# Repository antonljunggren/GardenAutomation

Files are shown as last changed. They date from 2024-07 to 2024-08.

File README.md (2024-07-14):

# Garden Automation System

A complete modular garden watering/monitoring system giving hobbyists and regular users a simple way to monitor and handle their gardens.

! STILL WIP !

## Overview
### Goals
In short, a complete system to handle everything from the sensors to the "cloud" automations

- Let users connect sensors in a simple way with a automated pairing process
- Be able to monitor the sensors on a dashboard
- Create automations or flows to let the system control sensors and outputs

## System Architecture
### Hardware

- Sensors will be simple MCUs like Attiny85 or similar (by using arduino supported MCUs a lot of problems will already been solved)
- A central hub consisting of a Raspberry Pi (hopefully a smaller Zero 2 will be sufficient enough)
- A CAN bus will be used for the communication between the devices and hub
- A perimiter wire that runs along the circumferense of the greenhouse that has: 24V power, CAN H & L and GND (24V for voltage drop, 12V, 5V & 3.3V are the target voltages on the devices/relays)

## Setup
To set up the raspberry pi we need to enable SPI and open a CAN bus interface in the boot config file. <br>
`dtparam=spi=on`<br>
`dtoverlay=mcp2515-can0,oscillator=16000000,interrupt=25,spimaxfrequency=1000000` <br>
`dtoverlay=spi-bcm2835-overlay`<br>

Then we install dotnet on the pi
`wget https://dot.net/v1/dotnet-install.sh -O dotnet-install.sh`<br>
`chmod +x dotnet-install.sh` <br>
`./dotnet-install.sh --channel 8.0 --install-dir /usr/share/dotnet` <br>
`export DOTNET_ROOT="/usr/share/dotnet"` <br>
`export PATH="$PATH:$DOTNET_ROOT"` <br>
`echo 'export DOTNET_ROOT=$HOME/.dotnet' >> ~/.bashrc` <br>
`echo 'export PATH=$PATH:$HOME/.dotnet' >> ~/.bashrc` <br>
`source ~/.bashrc` <br>

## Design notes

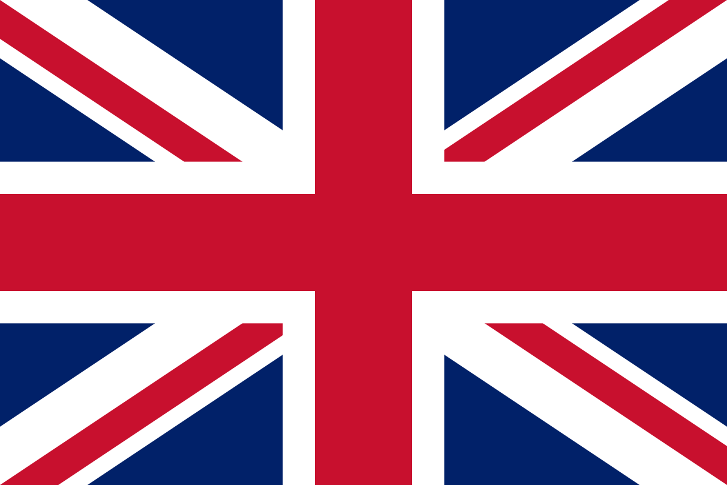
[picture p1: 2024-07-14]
Hub/src/WebAPI/Client/src/assets/uk_flag.png

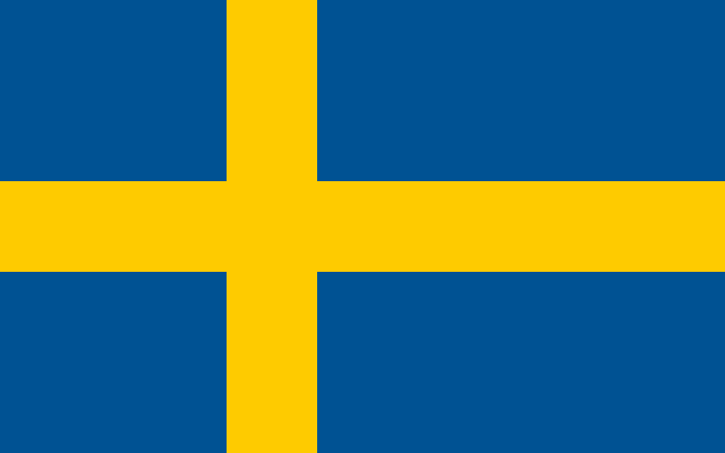
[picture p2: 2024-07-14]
Hub/src/WebAPI/Client/src/assets/swe_flag.png

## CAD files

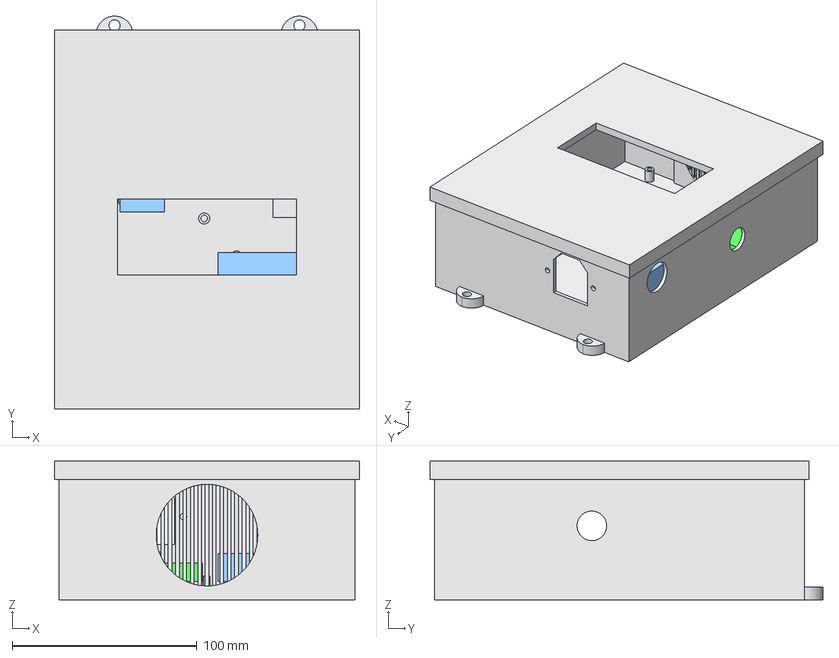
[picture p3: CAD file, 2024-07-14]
CAD/HubCad.FCStd
165.0 x 212.5 x 75.0 mm

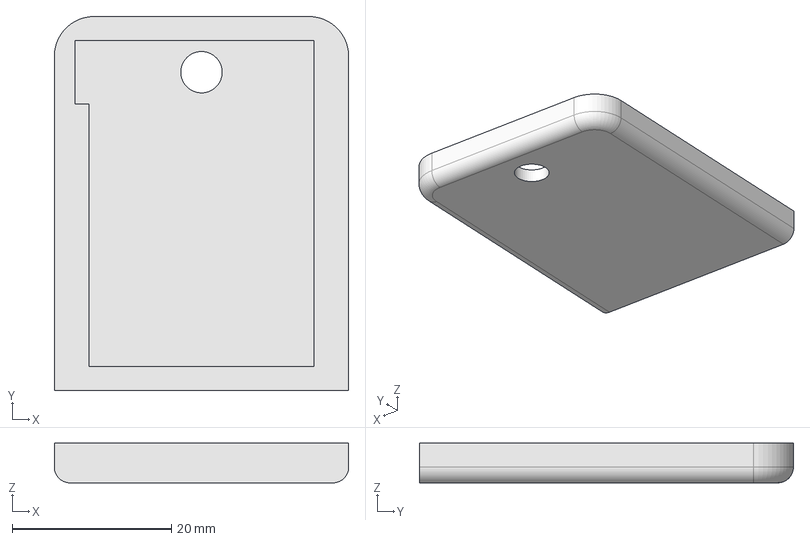
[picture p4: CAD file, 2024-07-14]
CAD/Generic_Attiny85_Sensor.FCStd
37.0 x 47.0 x 5.00 mm

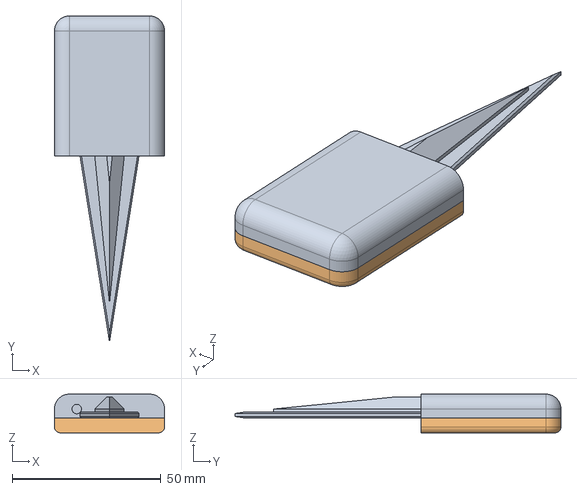
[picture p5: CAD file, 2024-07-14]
CAD/Attiny85_TemperatureSensor_Shell.FCStd
37.0 x 109.5 x 13.0 mm

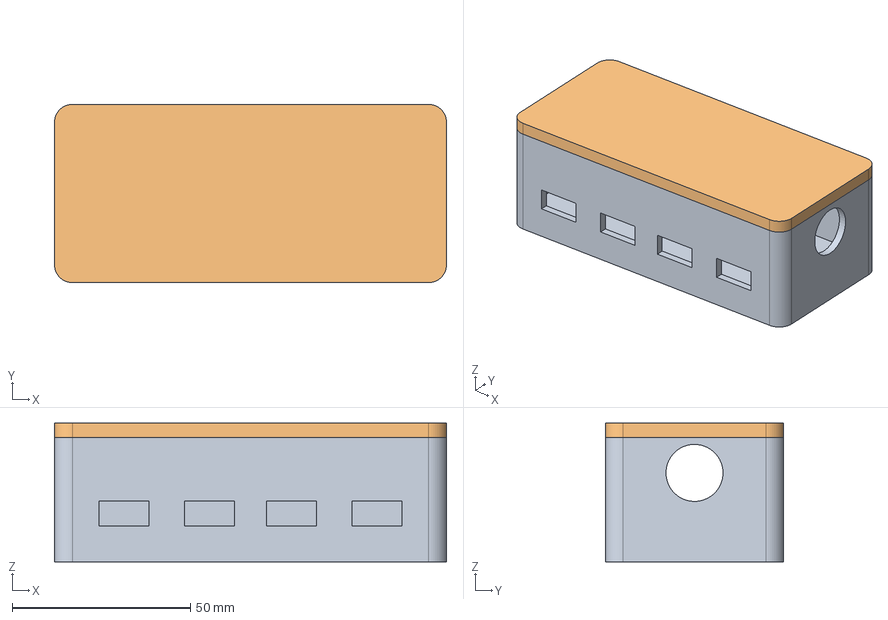
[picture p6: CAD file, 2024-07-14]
CAD/GatewayCAD.FCStd
110.0 x 50.0 x 39.0 mm

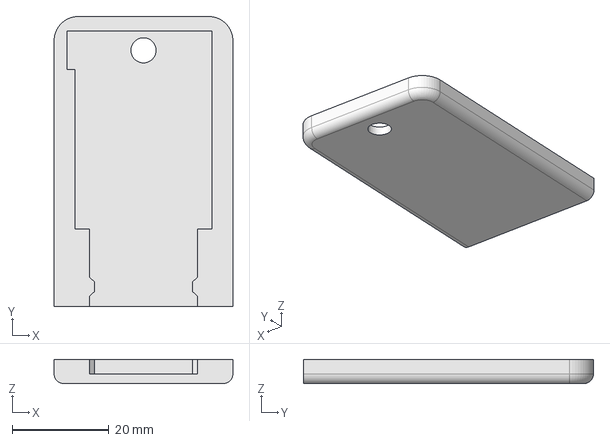
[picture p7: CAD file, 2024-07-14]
CAD/Attiny85_Soil_Moisture_Sensor.FCStd
37.0 x 60.0 x 5.00 mm

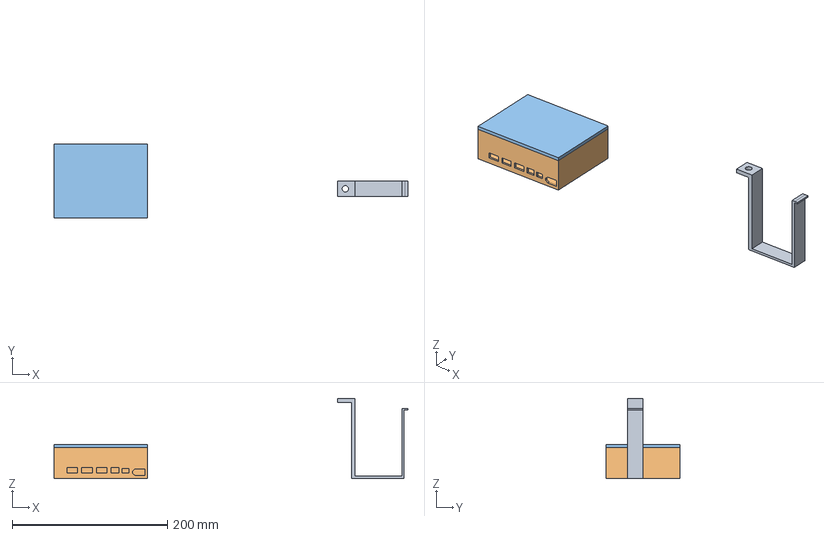
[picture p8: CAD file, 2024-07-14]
CAD/WaterPump.FCStd
455.5 x 95.0 x 103.0 mm

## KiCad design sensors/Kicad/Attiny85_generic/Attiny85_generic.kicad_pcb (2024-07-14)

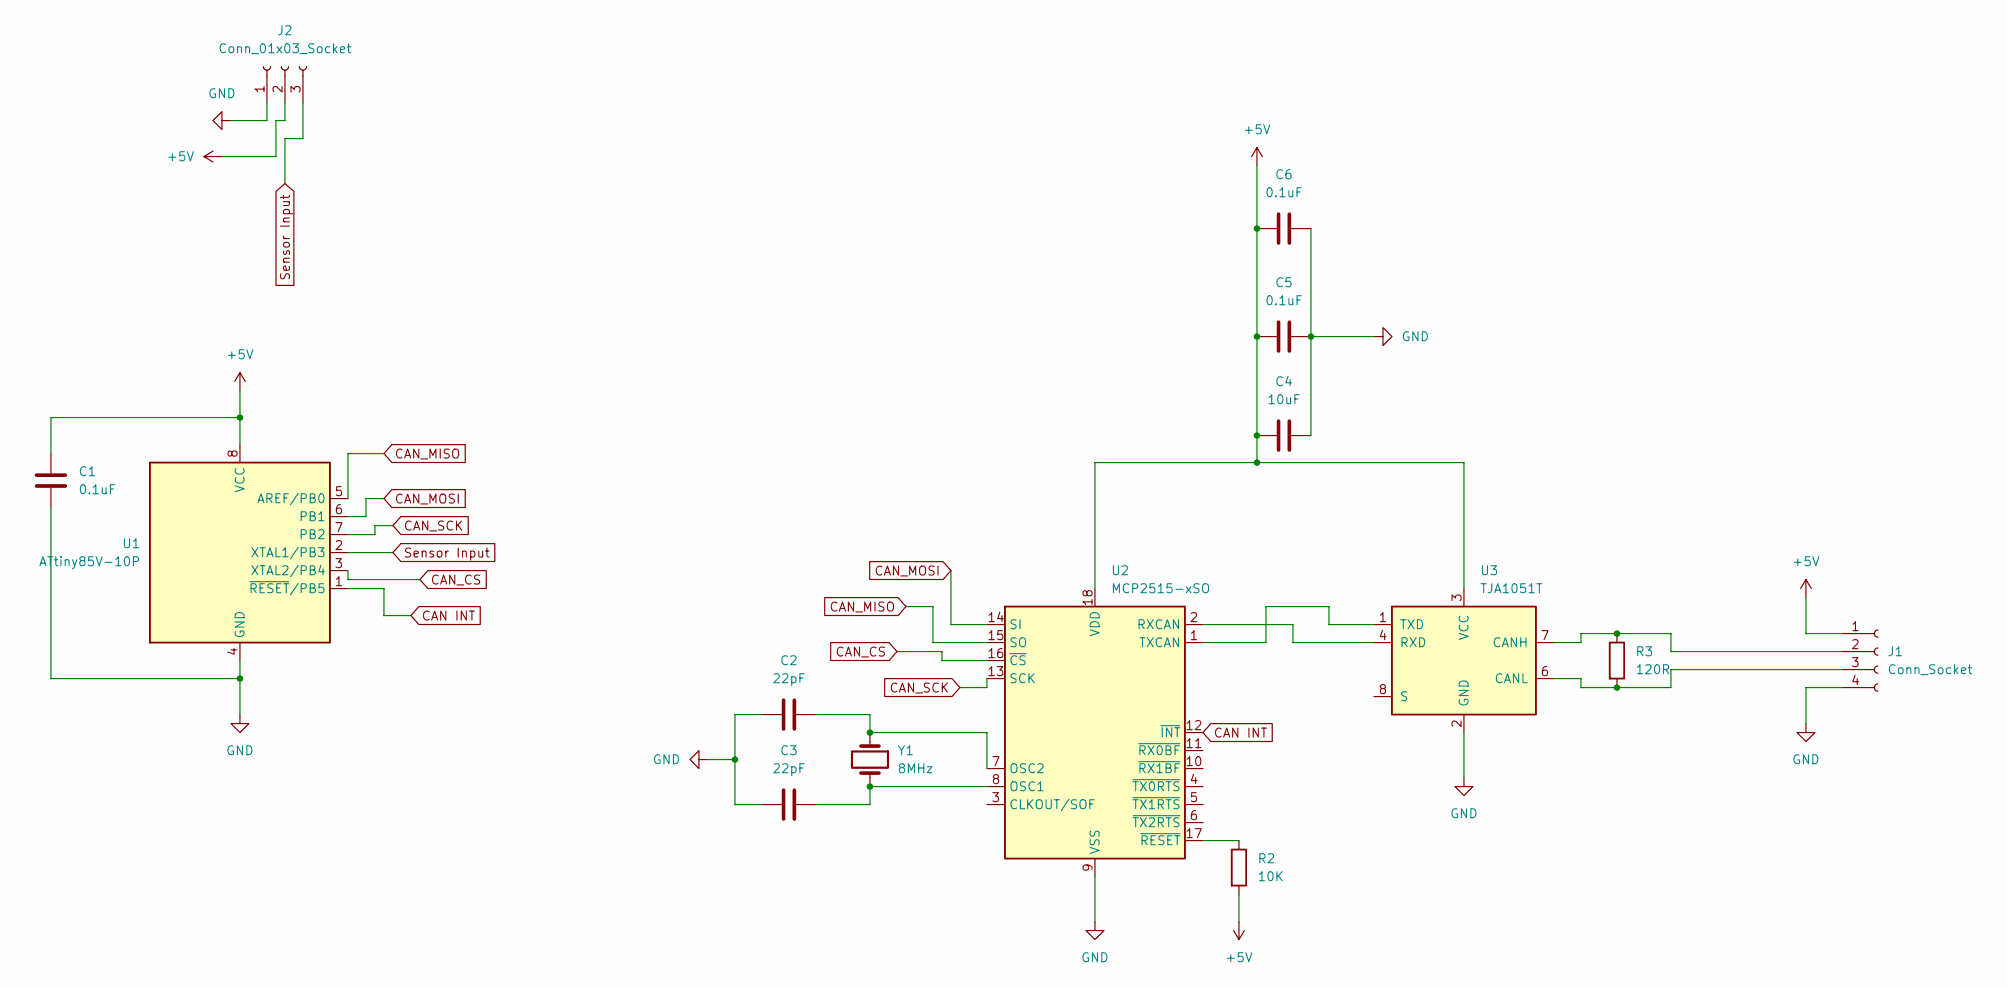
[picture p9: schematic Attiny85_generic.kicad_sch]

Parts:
C1, C5, C6: 0.1uF; C_0805_2012Metric_Pad1.18x1.45mm_HandSolder
C2, C3: 22pF; C_0805_2012Metric_Pad1.18x1.45mm_HandSolder
C4: 10uF; C_0805_2012Metric_Pad1.18x1.45mm_HandSolder
J1: Conn_Socket; PinHeader_1x04_P2.54mm_Vertical
J2: Conn_01x03_Socket; PinHeader_1x03_P2.54mm_Vertical
R2: 10K; R_0805_2012Metric_Pad1.20x1.40mm_HandSolder
R3: 120R; R_0805_2012Metric_Pad1.20x1.40mm_HandSolder
U1: ATtiny85V-10P; DIP-8_W7.62mm
U2: MCP2515-xSO; SOIC-18W_7.5x11.6mm_P1.27mm
U3: TJA1051T; SOIC-8_3.9x4.9mm_P1.27mm
Y1: 8MHz; Crystal_HC49-4H_Vertical

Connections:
+5V: C1.1, C4.2, C5.2, C6.2, J1.1, J2.2, R2.2, U1.8 (VCC), U2.18 (VDD), U3.3 (VCC)
CAN INT: U1.1 (~RESET/PB5), U2.12 (~INT)
CAN_CS: U1.3 (XTAL2/PB4), U2.16 (~CS)
CAN_MISO: U1.5 (AREF/PB0), U2.15 (SO)
CAN_MOSI: U1.6 (PB1), U2.14 (SI)
CAN_SCK: U1.7 (PB2), U2.13 (SCK)
GND: C1.2, C2.2, C3.2, C4.1, C5.1, C6.1, J1.4, J2.1, U1.4 (GND), U2.9 (VSS), U3.2 (GND)
unnamed: J1.2, R3.1, U3.7 (CANH)
unnamed: J1.3, R3.2, U3.6 (CANL)
unnamed: C3.1, U2.8 (OSC1), Y1.2
unnamed: C2.1, U2.7 (OSC2), Y1.1
unnamed: U2.2 (RXCAN), U3.4 (RXD)
unnamed: U2.1 (TXCAN), U3.1 (TXD)
unnamed: R2.1, U2.17 (~RESET)
Sensor Input: J2.3, U1.2 (XTAL1/PB3)

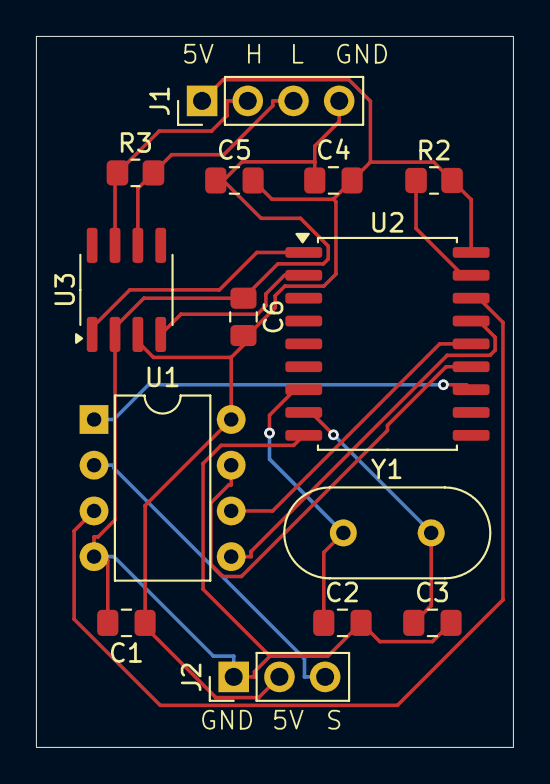
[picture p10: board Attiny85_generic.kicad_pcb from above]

Board: 2 copper layers, 26.5 x 39.5 mm, 14 parts (0 on the bottom side), 15 nets.

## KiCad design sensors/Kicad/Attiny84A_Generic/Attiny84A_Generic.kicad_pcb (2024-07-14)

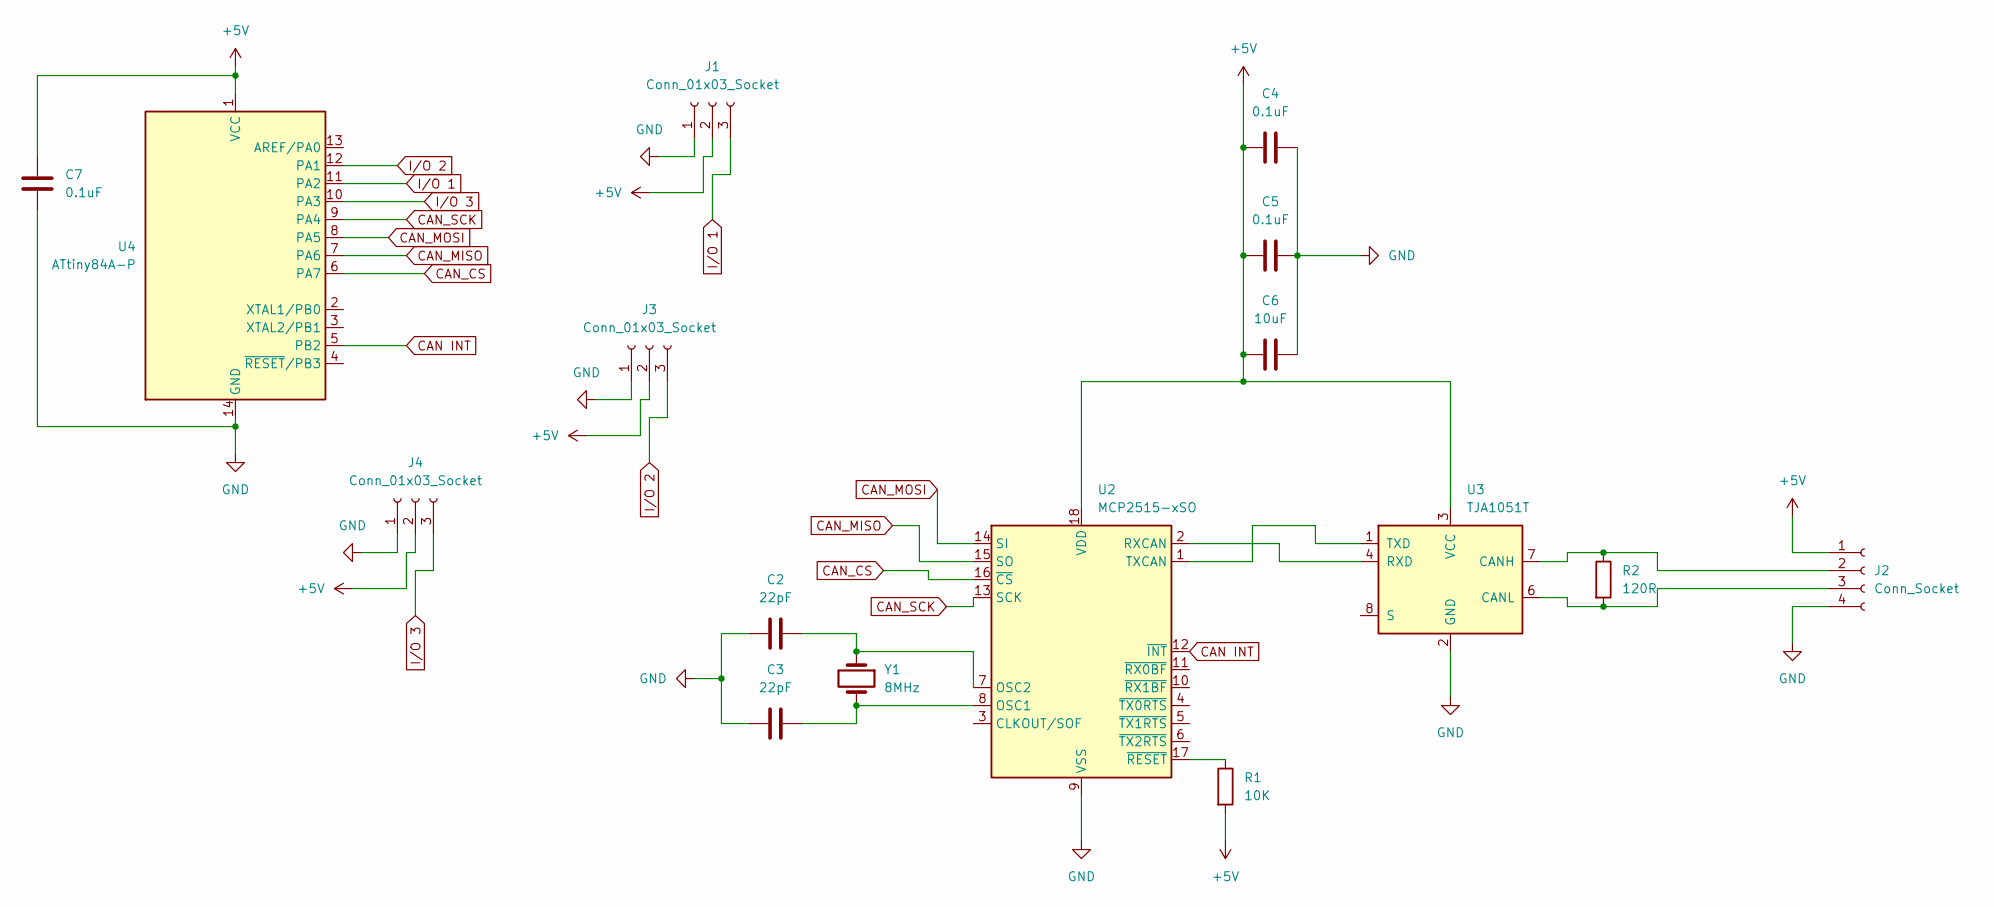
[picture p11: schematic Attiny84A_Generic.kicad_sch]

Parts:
C2, C3: 22pF; C_0805_2012Metric_Pad1.18x1.45mm_HandSolder
C4, C5, C7: 0.1uF; C_0805_2012Metric_Pad1.18x1.45mm_HandSolder
C6: 10uF; C_0805_2012Metric_Pad1.18x1.45mm_HandSolder
J1, J3, J4: Conn_01x03_Socket; PinHeader_1x03_P2.54mm_Vertical
J2: Conn_Socket; PinHeader_1x04_P2.54mm_Vertical
R1: 10K; R_0805_2012Metric_Pad1.20x1.40mm_HandSolder
R2: 120R; R_0805_2012Metric_Pad1.20x1.40mm_HandSolder
U2: MCP2515-xSO; SOIC-18W_7.5x11.6mm_P1.27mm
U3: TJA1051T; SOIC-8_3.9x4.9mm_P1.27mm
U4: ATtiny84A-P; DIP-14_W7.62mm
Y1: 8MHz; Crystal_HC49-4H_Vertical

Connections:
+5V: C4.2, C5.2, C6.2, C7.1, J1.2, J2.1, J3.2, J4.2, R1.2, U2.18 (VDD), U3.3 (VCC), U4.1 (VCC)
CAN INT: U2.12 (~INT), U4.5 (PB2)
CAN_CS: U2.16 (~CS), U4.6 (PA7)
CAN_MISO: U2.15 (SO), U4.7 (PA6)
CAN_MOSI: U2.14 (SI), U4.8 (PA5)
CAN_SCK: U2.13 (SCK), U4.9 (PA4)
GND: C2.2, C3.2, C4.1, C5.1, C6.1, C7.2, J1.1, J2.4, J3.1, J4.1, U2.9 (VSS), U3.2 (GND), U4.14 (GND)
I/O 1: J1.3, U4.11 (PA2)
I/O 2: J3.3, U4.12 (PA1)
I/O 3: J4.3, U4.10 (PA3)
unnamed: J2.2, R2.1, U3.7 (CANH)
unnamed: J2.3, R2.2, U3.6 (CANL)
unnamed: C3.1, U2.8 (OSC1), Y1.2
unnamed: C2.1, U2.7 (OSC2), Y1.1
unnamed: U2.2 (RXCAN), U3.4 (RXD)
unnamed: U2.1 (TXCAN), U3.1 (TXD)
unnamed: R1.1, U2.17 (~RESET)

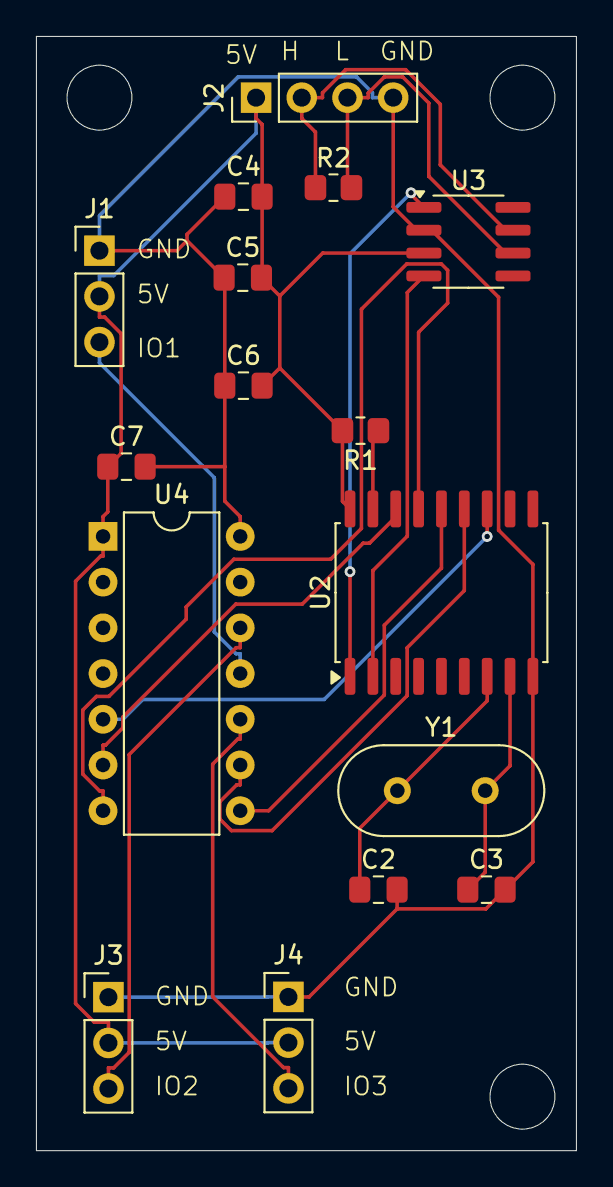
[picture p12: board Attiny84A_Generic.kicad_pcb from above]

Board: 2 copper layers, 30.0 x 61.9 mm, 16 parts (0 on the bottom side), 17 nets.

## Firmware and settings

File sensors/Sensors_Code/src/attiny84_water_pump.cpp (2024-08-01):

#include <sensor-device.h>
#include <EEPROM.h>

#define WATER_PUMP_PIN PIN_PA1
#define WATER_LEVEL PIN_PA3
#define WATER_LEVEL_STOP PIN_PA2

#define PUMP_CMD 0
#define SET_LOW_OFFSET_CMD 1
#define SET_MAX_OFFSET_CMD 2

#define DATA_WATER_LEVEL 0

#define NUMSAMPLES 10
int samples[NUMSAMPLES];

const int water_level_low_offset_address = 0;
const int water_level_max_offset_address = sizeof(int);

void dataReceived(CAN_Message msg);

int getWaterLevel();

void readFromEEPROM(int &low_offset, int &max_offset) {
  EEPROM.get(water_level_low_offset_address, low_offset);
  EEPROM.get(water_level_max_offset_address, max_offset);
}

bool is_pumping = false;

int lowOffset, maxOffset;

void setup()
{
    pinMode(WATER_PUMP_PIN, OUTPUT);
    pinMode(WATER_LEVEL, INPUT);
    pinMode(WATER_LEVEL_STOP, INPUT_PULLUP);

    digitalWrite(WATER_PUMP_PIN, LOW);
    delay(100);

    init_sensor(DEVICE_TYPE_WATER_PUMP, dataReceived);

    digitalWrite(WATER_PUMP_PIN, LOW);

    readFromEEPROM(lowOffset, maxOffset);
}

void loop()
{
    // tempValue = (int)(temp() * 100.0f);

    if(is_pumping && digitalRead(WATER_LEVEL_STOP) == LOW) {
        is_pumping = false;
        digitalWrite(WATER_PUMP_PIN, is_pumping);
        send_data(MSG_TYPE_DEVICE_STATE, 0);
        send_data(MSG_TYPE_DATA, 0.0f, DATA_WATER_LEVEL);
    }
    
    delay(500);
}

void dataReceived(CAN_Message msg)
{
    uint8_t commandType = msg.data[msg.dataLegth-2];
    uint8_t commandValue = msg.data[msg.dataLegth-1];

    if(msg.messageType == MSG_TYPE_CMD) {
        if(commandType == PUMP_CMD) {

            if(digitalRead(WATER_LEVEL_STOP) == LOW) {
                send_data(MSG_TYPE_DEVICE_STATE, 0);
                send_data(MSG_TYPE_DATA, 0, DATA_WATER_LEVEL);
                return;
            }

            digitalWrite(WATER_PUMP_PIN, commandValue);
            is_pumping = commandValue;
            send_data(MSG_TYPE_DEVICE_STATE, (int)commandValue);
            send_data(MSG_TYPE_DATA, getWaterLevel(), DATA_WATER_LEVEL);
        }
        else if(commandType == SET_LOW_OFFSET_CMD) {
            int currentLevel = analogRead(analogInputToDigitalPin(WATER_LEVEL));
            EEPROM.put(water_level_low_offset_address, currentLevel);
            lowOffset = currentLevel;
        }
        else if(commandType == SET_MAX_OFFSET_CMD) {
            int currentLevel = analogRead(analogInputToDigitalPin(WATER_LEVEL));
            EEPROM.put(water_level_max_offset_address, currentLevel);
            maxOffset = currentLevel;
        }
    }
    else if(msg.messageType == MSG_TYPE_DATA) {

        //default data, send water level
        if(digitalRead(WATER_LEVEL_STOP) == LOW) {
            send_data(MSG_TYPE_DATA, 0.0f, DATA_WATER_LEVEL);
        } else {
            send_data(MSG_TYPE_DATA, getWaterLevel(), DATA_WATER_LEVEL);
        }
    }
}

int getWaterLevel()
{
    uint8_t i;
    int average;

    for (i = 0; i < NUMSAMPLES; i++)
    {
        samples[i] = analogRead(analogInputToDigitalPin(WATER_LEVEL));
        delay(20);
    }

    average = 0;
    for (i = 0; i < NUMSAMPLES; i++)
    {
        average += samples[i];
    }
    average /= NUMSAMPLES;

    if(average < lowOffset) {
        return 0;
    }

    if(average > maxOffset) {
        return 1023;
    }

    return (average - lowOffset) * 1023L / (maxOffset - lowOffset);
}

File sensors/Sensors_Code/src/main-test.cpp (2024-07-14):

#include <SPI.h>
#include <mcp_can.h>

MCP_CAN CAN0(4);

#define LED_PIN 3

void setup()
{
    // Serial.begin(115200);
    pinMode(LED_PIN, OUTPUT);
    digitalWrite(LED_PIN, LOW);

    // Initialize MCP2515 running at 16MHz with a baudrate of 500kb/s and the masks and filters disabled.
    if (CAN0.begin(MCP_ANY, CAN_500KBPS, MCP_16MHZ) == CAN_OK)
        Serial.println("MCP2515 Initialized Successfully!");
    else
    {
        digitalWrite(LED_PIN, HIGH);
        delay(500);
        digitalWrite(LED_PIN, LOW);
        delay(500);
    }

    CAN0.setMode(MCP_NORMAL); // Change to normal mode to allow messages to be transmitted
}

byte data[8] = {0x12, 0x01, 0x02, 0x03, 0x04, 0x05, 0x06, 0x14};

void loop()
{
    // send data:  ID = 0x100, Standard CAN Frame, Data length = 8 bytes, 'data' = array of data bytes to send
    byte sndStat = CAN0.sendMsgBuf(0x100, 0, 8, data);
    if (sndStat == CAN_OK)
    {
        // Serial.println("Message Sent Successfully!");
        digitalWrite(LED_PIN, HIGH);
        delay(1000);
        digitalWrite(LED_PIN, LOW);
        delay(1000);
    }
    else
    {
        // Serial.println("Error Sending Message...");
    }
    delay(1000); // send data per 1000ms
}

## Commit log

2024-07-14 init commit new repo, messed up history on old
    [Attiny84A_Generic.kicad_pcb, Attiny84A_Generic.kicad_sch, Attiny85_Soil_Moisture_Sensor.FCStd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]
2024-07-14 removed systemId generation push to random logic app, as it is removed, got the id from deployed device
2024-07-15 updated telemetry data to identify what device the data comes from
2024-07-15 added a connect to cloud prop to settings, is set to opt out for testing will be opt in.
2024-07-15 added telemetry for water pump state
2024-07-17 fixed soil moisture sensor datat ype on measured point
2024-07-23 moved control devices to root of core project
2024-07-23 added exists calls for device repositories
2024-08-01 updated water pump code to smooth out input data
2024-08-03 added action scheduling for water pump to pump for x minutes
2024-08-03 split device fetching into separate lists for sensors and devices, added time display for action duration on devices
